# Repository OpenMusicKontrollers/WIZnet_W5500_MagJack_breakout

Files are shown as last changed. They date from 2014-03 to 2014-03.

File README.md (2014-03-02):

# WIZnet W5500 MagJack breakout 

## About
This is the PCB design of a breakout board for [WIZnet](http://www.wiznet.co.kr)'s 
[W5500](http://wizwiki.net/wiki/doku.php?id=products:w5500:start) hardwired TCP/IP chip with a MagJack for DIY production.

## Prerequisites
To be used with [KiCAD](http://www.kicad-pcb.org).

## License
This is open source hardware and licensed under [CERN OHL v.1.2](http://ohwr.org/cernohl).

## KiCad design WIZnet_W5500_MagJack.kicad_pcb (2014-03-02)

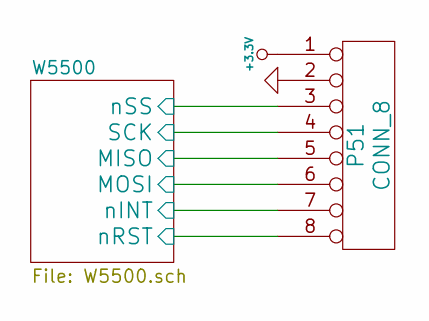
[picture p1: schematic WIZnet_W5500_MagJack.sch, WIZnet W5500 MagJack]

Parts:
P51: CONN_8

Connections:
+3.3V: P51.1; also elsewhere on the board
/W5500/MISO: P51.5; also elsewhere on the board
/W5500/MOSI: P51.6; also elsewhere on the board
/W5500/SCK: P51.4; also elsewhere on the board
/W5500/nINT: P51.7; also elsewhere on the board
/W5500/nRST: P51.8; also elsewhere on the board
/W5500/nSS: P51.3; also elsewhere on the board
GND: P51.2; also elsewhere on the board

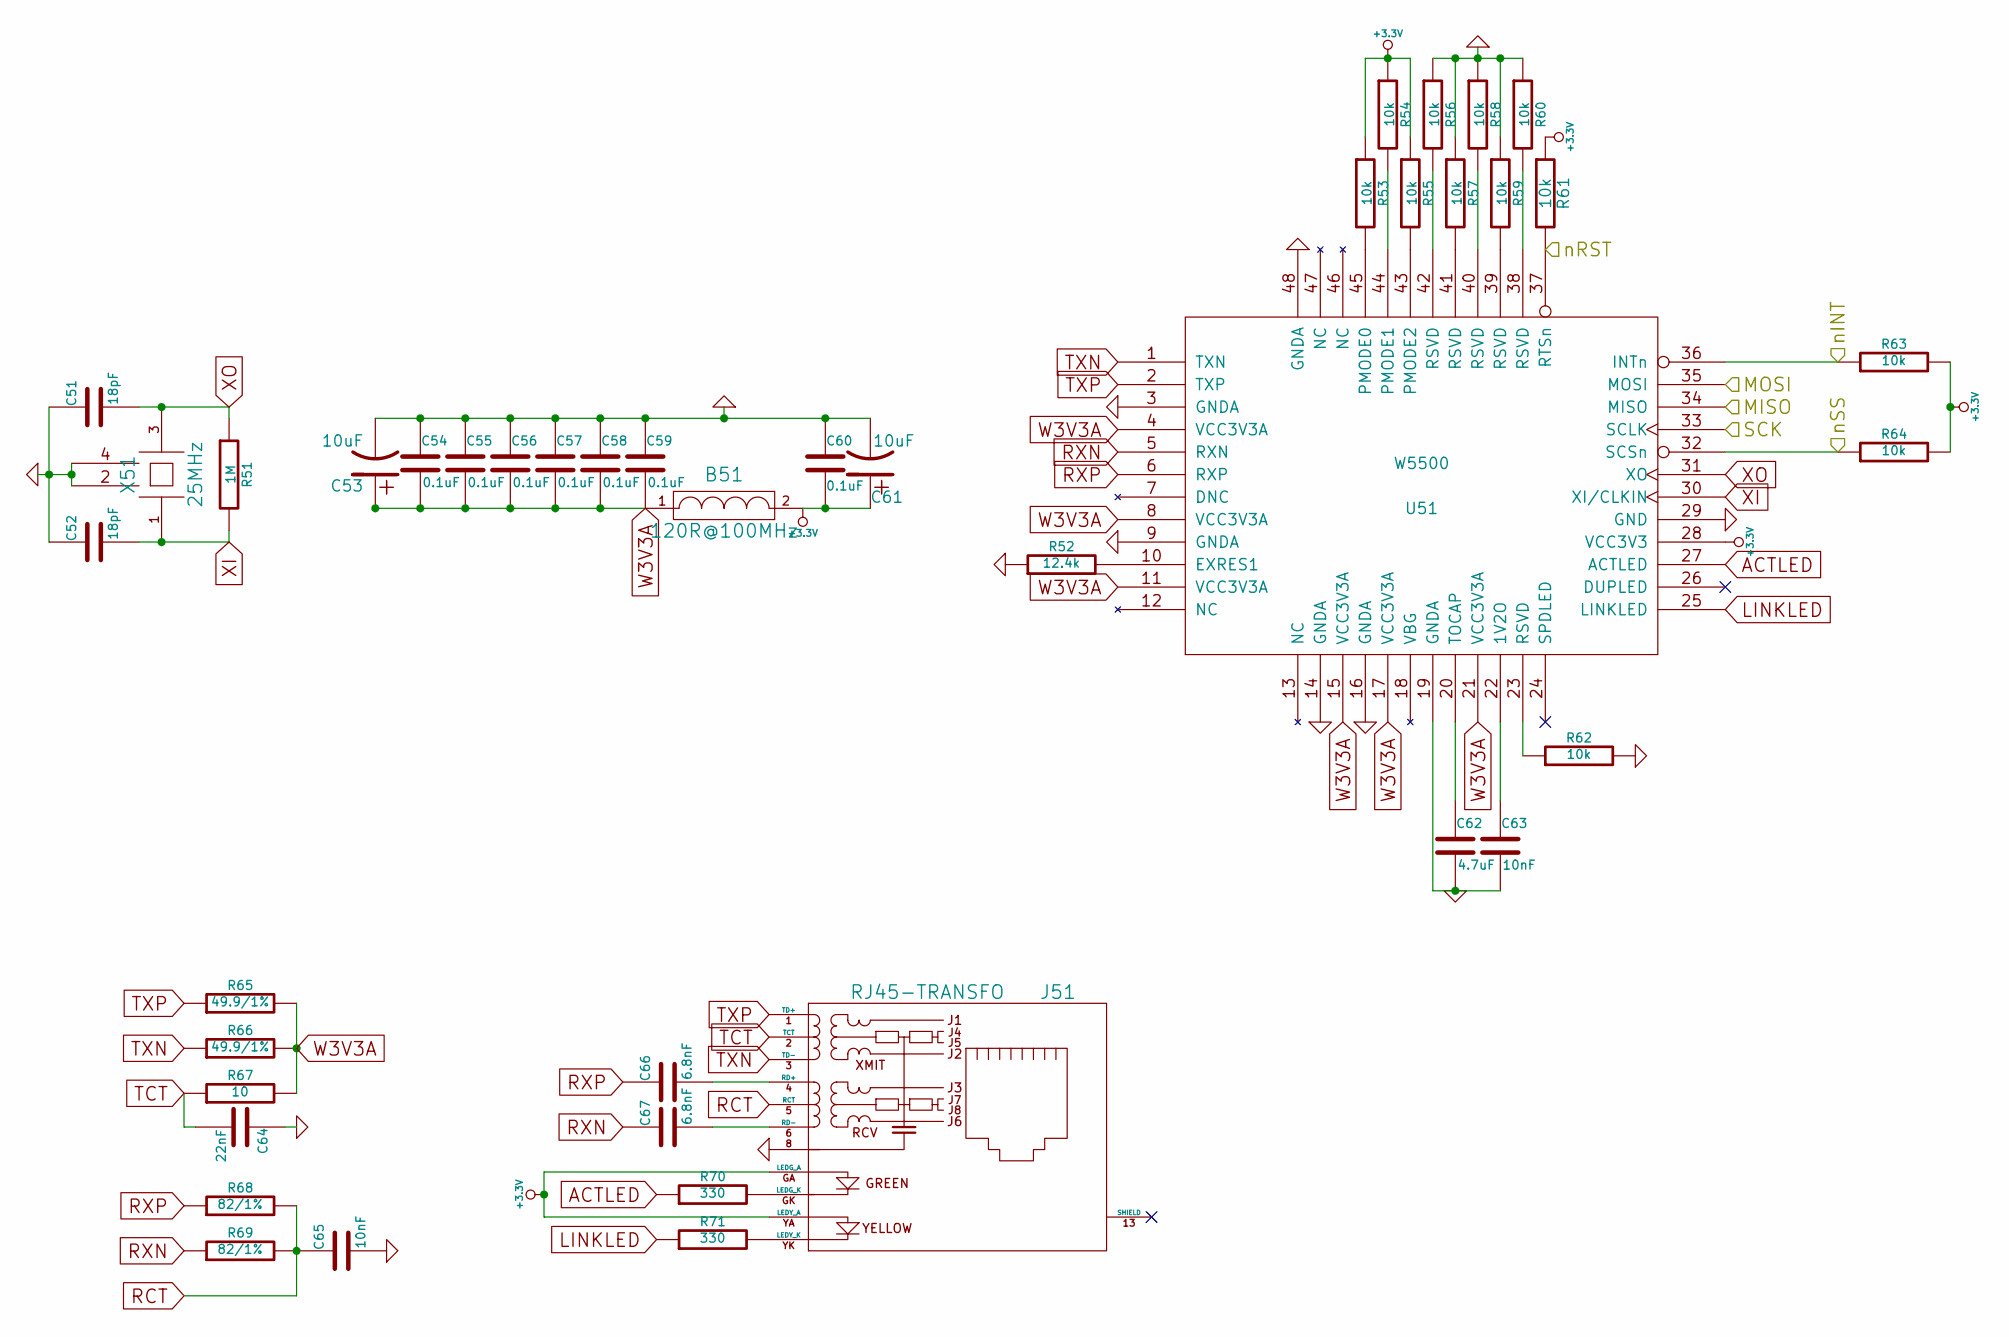
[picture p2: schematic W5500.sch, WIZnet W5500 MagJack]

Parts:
B51: 120R@100MHz; Digi-Key 240-2383-1-ND
C51, C52: 18pF; Digi-Key 311-1061-1-ND
C53, C61: 10uF; Digi-Key 478-8456-1-ND
C54, C55, C56, C57, C58, C59, C60: 0.1uF; Digi-Key 445-1314-1-ND
C62: 4.7uF; Digi-Key 445-6859-1-ND
C63, C65: 10nF; Digi-Key 311-1572-1-ND
C64: 22nF; Digi-Key 311-1370-1-ND
C66, C67: 6.8nF; Digi-Key 311-1084-1-ND
J51: RJ45-TRANSFO; Digi-Key 380-1106-ND
R51: 1M; Digi-Key P1.00MHCT-ND
R52: 12.4k; Digi-Key P12.4KHCT-ND
R53, R54, R55, R56, R57, R58, R59, R60, R62, R63, R64: 10k; Digi-Key P10KGCT-ND
R61: 10k; Digi-Key P10KGCT-ND
R65, R66: 49.9/1%; Digi-Key P49.9HCT-ND
R67: 10; Digi-Key P10.0HCT-ND
R68, R69: 82/1%; Digi-Key P82.0HCT-ND
R70, R71: 330; Digi-Key P330HCT-ND
U51: W5500; MODULE; Digi-Key 1278-1021-ND
X51: 25MHz; Digi-Key CTX826CT-ND

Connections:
+3.3V: B51.2, C60.2, C61.1, J51.GA (LEDG_A), J51.YA (LEDY_A), R53.1, R54.1, R55.1, R61.1, R63.2, R64.2, U51.28 (VCC3V3); also elsewhere on the board
/W5500/MISO: U51.34 (MISO); also elsewhere on the board
/W5500/MOSI: U51.35 (MOSI); also elsewhere on the board
/W5500/SCK: U51.33 (SCLK); also elsewhere on the board
/W5500/nINT: R63.1, U51.36 (INTn); also elsewhere on the board
/W5500/nRST: R61.2, U51.37 (RTSn); also elsewhere on the board
/W5500/nSS: R64.1, U51.32 (SCSn); also elsewhere on the board
ACTLED: R70.1, U51.27 (ACTLED)
GND: C51.1, C52.1, C53.2, C54.1, C55.1, C56.1, C57.1, C58.1, C59.1, C60.1, C61.2, C62.2, C63.2, C64.1, C65.2, J51.8, R52.1, R56.1, R57.1, R58.1, R59.1, R60.1, R62.2, U51.3 (GNDA), U51.9 (GNDA), U51.14 (GNDA), U51.16 (GNDA), U51.19 (GNDA), U51.29 (GND), U51.48 (GNDA), X51.2 (GND), X51.4 (GND); also elsewhere on the board
LINKLED: R71.1, U51.25 (LINKLED)
unnamed: R54.2, U51.44 (PMODE1)
unnamed: C63.1, U51.22 (1V2O)
unnamed: C62.1, U51.20 (TOCAP)
unnamed: R59.2, U51.39 (RSVD)
unnamed: R60.2, U51.38 (RSVD)
unnamed: C67.2, J51.6 (RD-)
unnamed: C66.2, J51.4 (RD+)
unnamed: R56.2, U51.42 (RSVD)
unnamed: R62.1, U51.23 (RSVD)
unnamed: R58.2, U51.40 (RSVD)
unnamed: R57.2, U51.41 (RSVD)
unnamed: R52.2, U51.10 (EXRES1)
unnamed: J51.GK (LEDG_K), R70.2
unnamed: R53.2, U51.45 (PMODE0)
unnamed: R55.2, U51.43 (PMODE2)
unnamed: J51.YK (LEDY_K), R71.2
RCT: C65.1, J51.5 (RCT), R68.2, R69.2
RXN: C67.1, R69.1, U51.5 (RXN)
RXP: C66.1, R68.1, U51.6 (RXP)
TCT: C64.2, J51.2 (TCT), R67.1
TXN: J51.3 (TD-), R66.1, U51.1 (TXN)
TXP: J51.1 (TD+), R65.1, U51.2 (TXP)
W3V3A: B51.1, C53.1, C54.2, C55.2, C56.2, C57.2, C58.2, C59.2, R65.2, R66.2, R67.2, U51.4 (VCC3V3A), U51.8 (VCC3V3A), U51.11 (VCC3V3A), U51.15 (VCC3V3A), U51.17 (VCC3V3A), U51.21 (VCC3V3A)
XI: C52.2, R51.2, U51.30 (XI/CLKIN), X51.1
XO: C51.2, R51.1, U51.31 (XO), X51.3

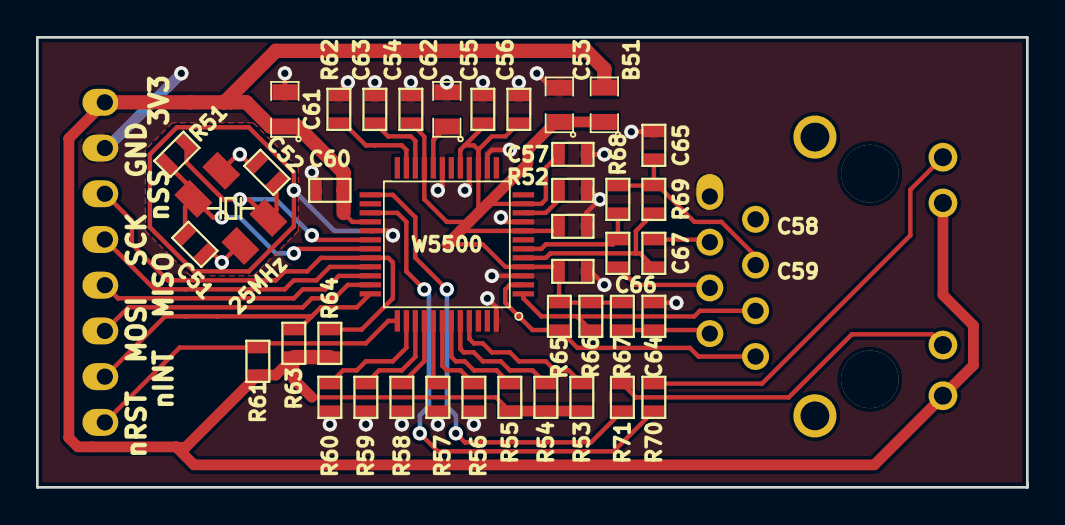
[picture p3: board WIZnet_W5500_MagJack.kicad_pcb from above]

Board: 2 copper layers, 55.0 x 25.0 mm, 43 parts (0 on the bottom side), 35 nets.

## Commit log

2013-11-25 polished W5500 integration, add AD75019
    [W5500.sch, WIZnet_W5500_MagJack.kicad_pcb, WIZnet_W5500_MagJack.sch]
2014-02-21 small updates to WIYnet W5500 breakout
    [W5500.sch, WIZnet_W5500_MagJack.kicad_pcb]
2014-03-02 solder paste clearence for 125um mylar stencils
    [WIZnet_W5500_MagJack.kicad_pcb]
2014-03-02 path fixes after repo split
    [WIZnet_W5500_MagJack.kicad_pcb]

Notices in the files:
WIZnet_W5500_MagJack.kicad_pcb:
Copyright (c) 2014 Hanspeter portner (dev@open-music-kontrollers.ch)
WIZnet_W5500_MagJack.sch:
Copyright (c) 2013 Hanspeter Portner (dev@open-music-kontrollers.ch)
